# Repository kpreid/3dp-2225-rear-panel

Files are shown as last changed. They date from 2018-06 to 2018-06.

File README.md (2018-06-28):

# What is it?

This is a 3D-printable replacement rear panel for a Tektronix 2225 CRT oscilloscope. If your scope, like mine, is missing its original plastic rear panel, this will provide:

* Rear feet. Rubber stick-on feet (≤ 14 mm diameter) can be inserted.
* Protection for the exposed end of the CRT.

It does not have any power cord management features.

It requires 180 mm × 132 mm of print area, and prints in two parts to glue together.

# Caveats

* This probably fits some other models but I'm not the historian to list exactly which ones.

* The rear handle/screw-hole areas lack support, and some of the interior cutouts are unnecessarily deep and nearly intersect the surface, meaning that some of the plastic will fall down and be ugly (but not enough to compromise the strength or cause the print to fail).

* This is not a particularly refined model; I just wanted to get it working and sturdy, and I didn't want to wait for many multi-hour prints. So the fit is not perfect and more plastic is used than probably necessary.

* My oscilloscope was also missing its front feet and pivoting handle. (I vaguely heard that this may be the result of it having been rack-mounted in the past.) Therefore, I have not attempted to match the height of the rear feet to the front, or test that they work with the scope tilted up.

# License

This work is licensed under a <a rel="license" href="https://creativecommons.org/licenses/by/4.0/">Creative Commons Attribution 4.0 International License</a>.

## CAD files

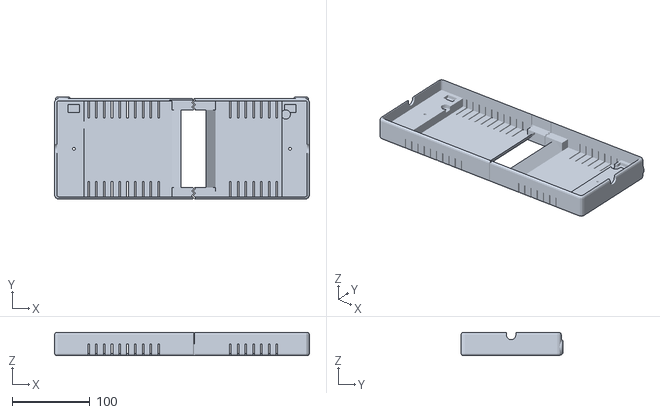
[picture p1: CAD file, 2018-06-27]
2225-rear-panel-4339f1f.stl
328.2 x 131.4 x 29.7

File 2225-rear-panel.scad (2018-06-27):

base_width = 320.0 + 0.25;  // measured mm, plus tweak after fitting
base_height = 123.5;  // measured mm
sleeve_depth = 15.0;  // chosen, overkill
general_thickness = 2.0;  // chosen
sleeve_thickness = 3;
back_face_depth = 12;  // chosen
sleeve_corner_round_radius = 2.5;  // measured mm

mounting_screw_x_inset = 22;  // measured
mounting_screw_hole_diameter = 4;  // #6 thread
mounting_screw_countersink_diameter = 10;  // overkill
mounting_screw_plate_depth = 3.0;  // chosen BUT NOT WELL
mounting_inset_thick = 5;
mounting_inset_width = 25;
mounting_inset_round = 6;

hook_width = 15;
hook_height = 10;
hook_depth = 4;
hook_y_inset = 5;  // measured mm

plate_start = 35;   // measured mm
plate_end = 134;  // measured mm
plate_depth = 8;  // measured mm

line_cord_start = 160.0;
line_cord_end = 190.0;
line_cord_y_clearance = 12.0;

crt_diameter = 70;  // measured mm, not used
crt_clearance_diameter = 75;  // picked
crt_depth = 10.21;  // measured mm, not used
crt_clearance_depth = 12;  // picked
crt_center_from_left = base_width - 70;  // measured mm

side_panel_screw_from_back = 11.5;

case_seam_width = 30;  // measured mm, generous overestimate
case_seam_thick = 1.2;

vent_slot_y_size = 20;
vent_spacing = 10;

epsilon = 0.01;
total_depth = sleeve_depth + back_face_depth;

cutaway_y = line_cord_y_clearance;
cutaway_height = base_height - line_cord_y_clearance * 2;

plastic_tab_from_left_1 = 128;
plastic_tab_from_left_2 = 197;
plastic_tab_clearance_size = [15, 7, 4];

two_pieces_flip();

// Cut into two pieces for reduced area requirements. Also flip over so that the flat side is down.
// If your printer is large enough and does not require layers to be supported from below, you can skip this and use main_one_piece().
module two_pieces_flip() {
    rotate([180, 0, 0])
    x_cut((line_cord_start + line_cord_end) / 2)
    main_one_piece();
}

module transition(x1, x2) {
    d = sign(x2 - x1);
    translate([x1, cutaway_y, 0])
    scale([1, -1, 1])
    rotate([90, 0, 0]) {
        linear_extrude(height=cutaway_height)
        polygon([
            [0, -epsilon],
            [x2 - x1, back_face_depth],
            [x2 - x1 + d*epsilon, back_face_depth],
            [x2 - x1 + d*epsilon, -epsilon]]);
        translate([0, 0, 0])
        linear_extrude(height=cutaway_height)
        polygon([
            [-d*epsilon, sleeve_thickness],
            [-d*epsilon, back_face_depth + sleeve_thickness + epsilon * 2],
            [x2 - x1, back_face_depth + sleeve_thickness + epsilon * 2],
            [x2 - x1 + epsilon, back_face_depth + sleeve_thickness + epsilon * 2],
            [0, sleeve_thickness]]);
    }
}

module roundcube_sphere(radius, size) {
    minkowski() {
        translate([radius, radius, radius])
        cube(size - [radius, radius, radius] * 2);
        sphere(r=radius);
    }
}

module roundcube_cylinder(radius, size) {
    minkowski() {
        translate([radius, radius, radius])
        cube(size - [radius, radius, radius] * 2);
        cylinder(r=radius, h=radius * 2, center=true, $fn=16);
    }
}

module left_mounting_screw_negative() {
    translate([mounting_screw_x_inset, base_height / 2, -epsilon])
    cylinder(d=mounting_screw_hole_diameter, h=total_depth);

    // countersink
    translate([mounting_screw_x_inset, base_height / 2, mounting_screw_plate_depth])
    cylinder(d=mounting_screw_countersink_diameter, h=total_depth);
    
    // add'l material clearance
    translate([mounting_inset_thick, mounting_inset_thick, mounting_inset_thick])
    roundcube_sphere(mounting_inset_round, [mounting_inset_width, base_height - mounting_inset_thick * 2, back_face_depth * 2]);
    
    // mounting hook
    translate([mounting_screw_x_inset - hook_width / 2, hook_y_inset, -epsilon])
    cube([hook_width, hook_height, hook_depth + epsilon]);
    
    // side panel attachment screws
    translate([0, base_height / 2, -side_panel_screw_from_back])
    rotate([0, -90, 0])
    hull() {
        screw_cutout_negative();
        translate([-1000, 0, 0])
        screw_cutout_negative();
    }
}

module screw_cutout_negative() {
    // diameter oversized for positioning error
    translate([0, 0, -epsilon])
    cylinder(d=12, h=5);
}

module foot_socket() {
    foot_dia = 14;
    wall = 1;
    depth = 2;
    corner_inset = 8;
    translate([corner_inset, 0, back_face_depth - corner_inset])
    rotate([90, 0, 0]) 
    scale([1, 1, 1]) {
        cylinder(d=foot_dia + wall * 2 + depth * 2, h=sleeve_thickness, $fn=32);

        translate([0, 0, sleeve_thickness]) 
        difference() {
            cylinder(d1=foot_dia + wall * 2 + depth * 2, d2=foot_dia + wall * 2, h=depth, $fn=32);
            cylinder(d=foot_dia, h=depth + epsilon, $fn=32);
        }
    }
}

module vertical_slot(x) {
    translate([x, -general_thickness * 2, 0])
        cube([general_thickness, vent_slot_y_size + sleeve_thickness * 2, back_face_depth * 3 - sleeve_thickness]);
    translate([x, base_height - vent_slot_y_size, 0]) 
        cube([general_thickness, vent_slot_y_size + sleeve_thickness * 2, back_face_depth * 3 - sleeve_thickness]);
}

module plastic_tab_clearance(x) {
    translate([x - plastic_tab_clearance_size.x / 2, base_height, -epsilon])
    mirror([0, 1, 0])
    cube(plastic_tab_clearance_size);
}

module main_one_piece() {
    crt_area_start = crt_center_from_left - crt_clearance_diameter / 2;
    
    // 45 degree slopes
    before_line_cord = max(plate_end, line_cord_start - back_face_depth);
    after_line_cord = min(crt_area_start, line_cord_end + back_face_depth);
    
    difference() {
        union() {
            // sleeve & surround
            translate([0, 0, -sleeve_depth + sleeve_thickness])
            minkowski() {
                roundcube_cylinder(sleeve_corner_round_radius, [
                    base_width,
                    base_height,
                    total_depth - sleeve_thickness]);
                sphere(r=sleeve_thickness);
            }
            
            // rubber foot cutout
            foot_socket();
            translate([base_width, 0, 0]) mirror([1, 0, 0]) foot_socket();
        }
        
        // hollow in sleeve for main body
        color("white")
        translate([0, 0, -sleeve_depth - epsilon])
          roundcube_cylinder(sleeve_corner_round_radius, [base_width, base_height, sleeve_depth + epsilon]);
        
        // mounting screws & matching things
        left_mounting_screw_negative();
        translate([base_width, 0, 0]) mirror([1, 0, 0]) left_mounting_screw_negative();
        
        // power transformer plate
        // using before_line_cord instead of plate_end to line up
        translate([plate_start, 0, -epsilon]) cube([before_line_cord - plate_start, base_height, max(plate_depth, back_face_depth) + epsilon]);
        
        // thinning out line cord area
        translate([line_cord_start, cutaway_y, sleeve_thickness]) cube([line_cord_end - line_cord_start, cutaway_height, back_face_depth + epsilon]);
        
        // hole punch for line cord (rough, not exact fitting)
        translate([line_cord_start, line_cord_y_clearance, -epsilon]) cube([line_cord_end - line_cord_start, base_height - line_cord_y_clearance * 2, back_face_depth + epsilon]);
        
        // CRT end -- fallback enforce-clearance
        translate([crt_center_from_left, base_height / 2, -epsilon])
            cylinder(r=crt_clearance_diameter / 2, h=crt_clearance_depth + epsilon);
        // CRT end -- broad material clearing
        translate([after_line_cord, 0, -epsilon]) cube([crt_clearance_diameter - after_line_cord + crt_area_start, base_height, back_face_depth + epsilon]);
        
        // ventilation slots
        for (i = [plate_start + 5/*fudge*/:vent_spacing:plate_end]) {
            vertical_slot(i);
        }
        for (i = [-crt_diameter / 2 + 5/*fudge*/:vent_spacing:crt_diameter / 2]) {
            vertical_slot(crt_center_from_left + i);
        }
        
        transition(line_cord_start, before_line_cord);
        transition(line_cord_end, after_line_cord);
        
        // heatsink screw near plate
        translate([31, 31.2, 0])
        screw_cutout_negative();
        // heatsink screws near crt
        translate([base_width - 27.51, 17.45, 0]) {
            screw_cutout_negative();
            translate([-25.2, 0, 0])
            screw_cutout_negative();
        }
        
        // plastic tabs sticking out back
        plastic_tab_clearance(plastic_tab_from_left_1);
        plastic_tab_clearance(plastic_tab_from_left_2);
        
        // case overlap seam
        translate([base_width / 2 - case_seam_width / 2, -case_seam_thick + epsilon, -sleeve_depth])
        cube([case_seam_width, case_seam_thick, sleeve_depth]);
        
        // don't have spaces for those upper side plastic frame tabs -- no, not needed as long as we are doing the 'airy' version
    }
}

// --- generic helpers
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

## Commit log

2016-12-21 Initial version.
    [2225-back-panel.scad]
2016-12-22 mounting hook
    [2225-back-panel.scad]
2016-12-22 non-default color for visibility
    [2225-back-panel.scad]
2016-12-22 remove stale TODO for mounting hooks
    [2225-back-panel.scad]
2016-12-22 power transformer plate
    [2225-back-panel.scad]
2016-12-22 oops had plate twice
    [2225-back-panel.scad]
2016-12-22 basic ventilation slots
    [2225-back-panel.scad]
2016-12-22 refined vertical vent slots
    [2225-back-panel.scad]
2016-12-22 polish, thicker sleeve, trim material from cutouts
    [2225-back-panel.scad]
2016-12-22 draft of slanted transitions
    [2225-back-panel.scad]
2016-12-22 polish of slanted transitions
    [2225-back-panel.scad]
2016-12-22 reversible transition
    [2225-back-panel.scad]
2016-12-22 get fancy around countersinks, tweak slots
    [2225-back-panel.scad]
2016-12-22 back_face_depth is now minus the thickness, because things work out better
    [2225-back-panel.scad]
2016-12-22 polish transition
    [2225-back-panel.scad]
2016-12-22 fix hook clearance positioning
    [2225-back-panel.scad]
2016-12-22 rounded box handle-hole-things
    [2225-back-panel.scad]
2016-12-22 fix edges of transition
    [2225-back-panel.scad]
2018-06-24 Add various missing measurements.
    [2225-back-panel.scad]
2018-06-24 Side panel screw cutouts.
    [2225-back-panel.scad]
2018-06-24 Split into two pieces for print size, add chunky contact surface.
    [2225-back-panel.scad]
2018-06-24 Roughen cut face.
    [2225-back-panel.scad]
2018-06-24 Flip over for FDM printing.
    [2225-back-panel.scad]
2018-06-24 Tweak feet and vents.
    [2225-back-panel.scad]
2018-06-24 Reduce material used.
    [2225-back-panel.scad]
2018-06-25 Round corners to match oscilloscope case.
    [2225-back-panel.scad]
2018-06-25 Make side screw cutouts straight edged.
    [2225-back-panel.scad]
2018-06-25 Notch for case seam; reduce epsilon (!!!).
    [2225-back-panel.scad]
2018-06-25 Tweak width after fitting.
    [2225-back-panel.scad]
2018-06-27 Notch for black plastic tabs.
    [2225-back-panel.scad]
2018-06-27 More info.
    [2225-rear-panel.scad]
2018-06-27 Include STL. This is a build product, but so convenient!
    [2225-rear-panel-4339f1f.stl]
